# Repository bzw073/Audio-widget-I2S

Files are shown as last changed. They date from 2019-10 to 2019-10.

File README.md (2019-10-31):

# Audio-widget-I2S
**Interfata audio USB utilizand un AVR32 pe protocolul I2S**

## Introducere
>
>Inca din timpurile dinaintea erei digitale, consumatorii de audio **asa zisii audiofili** au fost in cautare de metode pentru reducerea la minim a distorsiunilor transmise catre difuzoare,si implicit,percepute de urechea umana.In vremea respectiva,data fiind si complexitatea destul de redusa a dispozitivelor,ideea reducerii distorsiunilor in sisteme era destul de limitata de topologiile propuse,de aceea aparitia sistemelor digitale de procesare in audio a dus la reducerea drastica a neajunsurilor semnalelor analogice.Pentru **puristi** , circuitele digitale si DSP-urile sunt considerate _un sacrilegiu_ adus audiofiliei,dar este unul justificat,deoarece in ciuda complexitatii mai ridicate fata de un circuit analog pur , sistemele digitale sunt mult mai eficiente fata de complementele sale,iar posibilitatea customizarii lor este foarte mare (spre deosebire de un circuit analogic unde,pentru a modifica o caracteristica trebuie regandit tot circuitul,in cazul unui circuit digital cu uC este doar o problema de software).

>Aparitia interfetelor audio s-a facut odata cu dezvoltarea PC-urilor si inregistrarea de muzica/sunete pe medii digitale , in pofida benzilor magnetice si a discurilor de vinil , deoarece era necesara o metoda de redare a sunetelor stocate pe calculatoarele vremii. De altfel,primele asa zise **placi de sunet** si-au facut aparitia prin calculatoare in jurul generatiei 80486 , cand deja exista o oarecare structura de operare stabila pe 16 biti , iar pentru o esantionare simpla a sunetelor erau arhisuficiente instructiunile implementate de Intel in procesoarele respective.
>>_Daca facem referinta la vremurile actuale,se poate spune ca practic nici nu se punea problema de calitate sau termenul de **Hi-Fi** in acele vremuri,dar acele sunete au reprezentat ceea ce urma sa fie boom-ul erei digitale_
>
>Ca si istorie a acestei ere in care traim,se pot scrie foarte multe lucruri deja cunoscute,asa ca voi incerca sa ma concentrez pe esential.

>Ideea de "calitate audio" pe digital a aparut in momentul lansarii pe piata mondiala a CD-ului (acel lucru care acum multora dintre noi ni se pare atat de outdated,ori chiar nu il mai folosim),dar el a avut cea mai mare influenta in aparitia de tehnologii de compresie si codare audio.Ca si concept,ideea de CD a aparut prin anul 1980 ,cand Philips si Sony au incheiat un parteneriat de cercetare in domeniul digital,dorindu-se un mediu de stocare unic transmisibil,care sa aibe un spatiu de stocare a informatiilor mult mai mare decat cel al dischetelor "floppy" si al benzilor magnetice,dar totusi sa nu coste cat un hard disk al vremurilor (memo: un hard disk de tip Winchester avea o capacitate de maxim 128MB , cantarea in jur de 15-20kg si era cam cat un desktop SFF actual ca dimensiuni si costa in jur de ~5.000 de dolari unul?).
>>Standardul CD a fost definitivat in jurul anului 1983,iar in urma intelegerii realizate intre cele 2 concerne se va realiza trecerea industriei audio catre acest mediu.

>Se pune problema "compresiei audio".In a nutshell,algoritmul de compresie audio se refera la un standard de scriere-redare a sunetelor pe calculatoare. Calculatoarele,la momentul respectiv avand sisteme de operare stabile precum UNIX si DOS (vorbind de anii '80,dar regula se aplica si in prezent pe sistemele actuale),pentru a reda sunetele stocate pe medii precum hard-diskul se folosesc de niste software numite **codec** .
>>Codecurile,in esenta,sunt niste pseudo-drivere pe care sistemul de operare le interpreteaza atunci cand se executa in sistem un fisier cu extensia ce corespunde codecului respectiv.
>>Adica,spre exemplu, avem un fisier cu extensia ".mp3" , SO va sti ca la instantierea acestui fisier va trebui sa apeleze un Codec LAME(Lame Ain't an MP3 Encoder - care este o derivatie imbunatatita de-a lungul anilor de diversi programatori din conceptul original gandit de institutul Fraunhofer din Germania).

>De altfel , toate procedeele de redare/compresie si extensiile de sistem au fost posibile datorita codarii PCM (Pulse Code Modulation).
PCM reprezinta transformarea semnalelor analogice in semnale digitale printr-un algoritm de esantionare constanta a amplitudinii semnalului analogic ,iar fiecare esantion este cuantizat la cea mai apropiata valoare dintr-o gama de cuante apropiate.
>>**Codarea PCM prezinta 2 proprietati ce determina calitatea conversiei semnalului original raportat la acesta : rata de esantionare a semnalului si _bit depth_,care reprezinta cantitatea de biti al fiecarui esantion realizat (un CD-Audio prezinta un bit depth de 16 biti per esantion , pe cand un Blu-ray sau DVD-Audio 24 de biti per esantion).**
>>> Extensiile posibile unei compresii PCM sunt ".wav" ,".L16",".PCM",".AIFF",".AU"

>Pe baza codarii/compresiei PCM a fisierelor audio, cei de la Philips au realizat in anul 1986 (si ulterior revizuit in 1996) un protocol de transmisie seriala al datelor audio intre dispozitive / circuite integrate , protocol care inca se foloseste cu succes si in prezent in dispozitivele audio. Este cunoscut sub acronimul I2S sau IIS **Inter-IC Sound** si se bazeaza pe o magistrala sincrona de transmisie de date (clockul de transmisie intre circuite este separat de magistrala de date,deci implicit receptorul nu mai are nevoie de un circuit suplimentar de refacere a frontului de ceas trimis de emitator).
>Protocolul este relativ usor de interpretat, in principal avem de-a face cu 3 semnale : bit clock line(**BCLK**) , word clock line (cunoscut sub denumirea oficiala de 'word select' **WS** sau 'left-right clock' **LRCLK** ) si cel putin o linie de date multiplexata **SD**

>>Adeseori se mai poate intalni peste cele 3 semnale cunoscute inca un semnal de tact (care nu face parte din protocol) cu rolul de a sincroniza operatiile interne ale DAC-urilor cu cele ale controllerului . Este gasit sub acronimul de "Master clock" **MCLK**
>>>Frecventa tipica de lucru se calculeaza dupa formula : **MCLK = 256 * LRCLK**

500px-I2S_Timing svg

###### Cum functioneaza protocolul:

>Semnalul de "Word Select" permite dispozitivului receptor sa 'vada' ce canal urmeaza sa fie trimis , deoarece I2S permite ca pe aceeasi linie de date sa fie trimise 2 canale,fiind un semnal cu factor de umplere 50% si frecventa egala cu cea de esantionare a semnalului trimis.
>>**Pentru semnale stereo , in brosura de specificatii a I2S se spune ca semnalul audio de pe canalul stang se transmite pe palierul de 0 al Word Select , iar canalul drept pe palierul de 1 . De obicei , semnalul "Word Select" este sincronizat dupa fronturile cazatoare ale semnalului BCLK , deoarece datele sunt zavorate pe fronturile crescatoare**.
>>
>Se stabileste semnul liniei de date si se codeaza in complement fata de 2 cu primul bit MSB-ul . **Acest lucru permite ca numarul de biti per cadru sa fie arbitrar , fara a fi nevoie de "negociere" intre emitator si receptor **.

## Specificatii montaj:

1.
 a)Microcontroller utilizat:  Atmel AT32UC3A3256 
 >>>  A complete system-on-chip 32-bit AVR microcontroller. It is designed for cost-sensitive embedded applications that require low power consumption, high code density and high performance.

 >>> The microcontroller's Memory Protection Unit (MPU) and fast, flexible interrupt controller support the latest real-time operating systems. Higher computation capabilities are achievable using a rich set of DSP instructions. The device incorporates on-chip flash and SRAM memories for secure and fast access. 64 KBytes of SRAM are directly coupled to the 32-bit AVR UC3 for performance optimization. Two blocks of 32 Kbytes SRAM are independently attached to the high speed bus matrix for real ping-pong management.

 >>> The microcontroller achieves exceptionally high data throughput by combining the multi-layered 32-bit AVR databus,128 KB on-chip SRAM with triple high speed interfaces, multi-channel peripheral, memory-to-memory DMA controller, high-speed USB embedded host, SD/SDIO card, MLC NAND flash with ECC, and SDRAM interfaces.

 >>> This device features 256KB internal high-speed flash and full-duplex multi-channel I2S audio interface.
 
 b) DAC utilizat: PCM5102A

 >>>The PCM510xA devices are a family of monolithic CMOS-integrated circuits that include a stereo digital-to-analog converter and additional support circuitry in a small TSSOP package. The PCM510xA devices use the latest generation of TI’s advanced segment-DAC architecture to achieve excellent dynamic performance and improved tolerance to clock jitter.

 c) Amplificator/buffer iesire folosit : TPA6120
 >>>In applications requiring a high-power output, very high fidelity headphone amplifier, the TPA6120A2 replaces a costly discrete design and allows music, not the amplifier, to be heard. The TPA6120A2’s current-feedback AB amplifier architecture delivers high bandwidth, extremely low noise, and up to 128dB of dynamic range.
 
2.Utilizeaza USB Audio Class 1 / 2.

3.Capabilitati de redare audio pana la 24bit/96kHz (bit depth / sampling rate).

4.Tensiune de alimentare: 5V

5.Consum max: 500mA 

### Constructie montaj:

Contructia se bazeaza pe un design modular , iar in acest sens voi concepe intregul sistem pe 4 placi:
 - una o va constitui interfata emulatoare usb-i2s
 - o placa pentru DAC si , eventual , buffere de iesire
 - o placa pentru amplificatorul final
 - o placa pentru alimentare suplimentara

Ideea conceperii montajului intr-un sistem modular este pentru imbunatatirea "lantului" pe decursul timpului (ex. realizarea unui DAC mai performant din perspectiva SNR / PSRR sau schimbarea unei surse liniare cu una in comutatie sau adaugarea de acumulatori pentru portabilitate etc.)

De altfel,un montaj modular poate presupune o asezare mai buna in cutie si,totodata, un ecranaj mai bun al partilor **mai sensibile** fata de circuitul de alimentare.

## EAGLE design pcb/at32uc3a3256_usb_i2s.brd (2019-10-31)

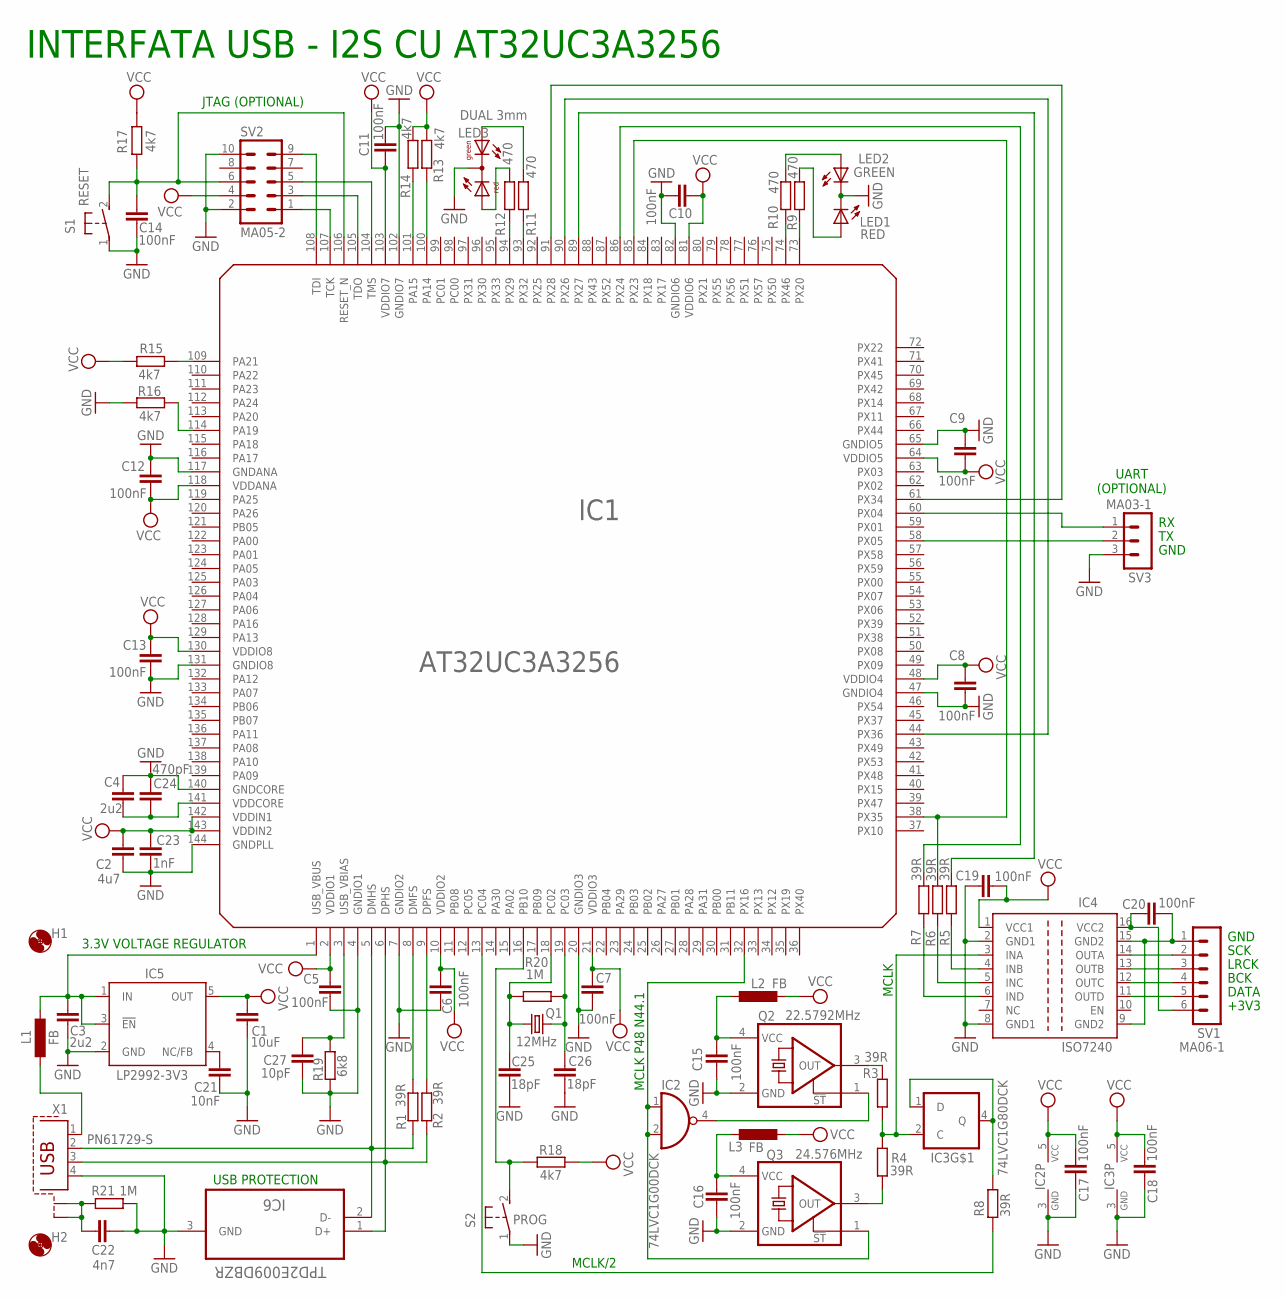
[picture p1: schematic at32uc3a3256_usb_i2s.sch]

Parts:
C1: 10uF; C0603
C2: 4u7; C0603
C3, C4: 2u2; C0603
C5, C6, C7, C8, C9, C10, C11, C12, C13, C14, C15, C16, C17, C18, C19, C20: 100nF; C0603
C21: 10nF; C0603
C22: 4n7; C0603
C23: 1nF; C0603
C24: 470pF; C0603
C25, C26: 18pF; C0603
C27: 10pF; C0603
H1, H2: MOUNT-HOLE3.2; 3,2
IC1: AT32UC3A3256; LQFP144
IC2: 74LVC1G00DCK; SC70-5
IC3: 74LVC1G80DCK; SC70-5
IC4: ISO7240; SO-16DW
IC5: LP2992-3V3; SOT23-DBV
IC6: TPD2E009DBZR; SOT95P237X112-3N
L1, L2, L3: FB; L2012C
LED1: RED; CHIPLED_0603
LED2: GREEN; CHIPLED_0603
LED3: DUAL 3mm; DUOLED5MM
Q1: 12MHz; CTS406
Q2: 22.5792MHz; CRYSTAL2.5X2
Q3: 24.576MHz; CRYSTAL2.5X2
R1, R2, R3, R4, R5, R6, R7, R8: 39R; R0603
R9, R10, R11, R12: 470; R0603
R13, R14, R15, R16, R17, R18: 4k7; R0603
R19: 6k8; R0603
R20, R21: 1M; R0603
S1: RESET; SWITCH-KSR
S2: PROG; SWITCH-KSR
SV1: MA06-1
SV2: MA05-2
SV3: MA03-1
X1: PN61729-S

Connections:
AD_LRCK: IC1.44 (PX36), IC1.90 (PX26)
AD_SCLK: IC1.61 (PX34), IC1.91 (PX28)
DA_LRCK: IC1.89 (PX27), R5.2
DA_SCLK: IC1.38 (PX35), IC1.85 (PX23), R6.2
GND: C1.2, C2.2, C3.2, C4.1, C5.2, C6.2, C7.2, C8.2, C9.1, C10.1, C11.1, C12.1, C13.1, C14.2, C15.1, C16.1, C17.2, C18.2, C19.1, C21.2, C22.2, C23.2, C24.1, C25.2, C26.2, C27.2, IC1.4 (GNDIO1), IC1.7 (GNDIO2), IC1.20 (GNDIO3), IC1.47 (GNDIO4), IC1.65 (GNDIO5), IC1.82 (GNDIO6), IC1.102 (GNDIO7), IC1.117 (GNDANA), IC1.131 (GNDIO8), IC1.140 (GNDCORE), IC1.144 (GNDPLL), IC2.3 (GND), IC3.3 (GND), IC4.2 (GND1), IC4.8 (GND1), IC5.2 (GND), IC6.3 (GND), LED1.C, LED2.C, LED3.K (C), Q2.2 (GND), Q3.2 (GND), R16.1, R19.1, R21.2, S1.1, S2.1, SV2.2, SV2.10, SV3.3, X1.4
GND2: C20.2, IC4.9 (GND2), IC4.15 (GND2), SV1.1
GPIO_05_LED2: IC1.94 (PX29), R12.1
GPIO_08_LED1: IC1.93 (PX32), R11.1
LRCK: IC4.4 (INB), R5.1
MCLK: IC3.2 (C), IC4.3 (INA), R3.1, R4.2
MCLK_MCU: IC1.13 (PC04), R8.1
MCLK_P48_N441: IC1.32 (PX16), IC2.1 (I0), IC2.2 (I1), Q3.1 (!ST)
unnamed: C15.2, L2.2, Q2.4 (VCC)
unnamed: IC1.5 (DMHS), IC6.2 (D-), R1.1, X1.2
unnamed: Q3.3 (OUT), R4.1
unnamed: Q2.3 (OUT), R3.2
unnamed: C16.2, L3.2, Q3.4 (VCC)
unnamed: IC1.6 (DPHS), IC6.1 (D+), R2.1, X1.3
unnamed: IC1.8 (DMFS), R1.2
unnamed: C26.1, IC1.19 (PC03), Q1.3 (2), R20.2
unnamed: C25.1, IC1.18 (PC02), Q1.1, R20.1
unnamed: IC1.9 (DPFS), R2.2
unnamed: C4.2, C24.2, IC1.141 (VDDCORE)
unnamed: IC1.108 (TDI), SV2.9
unnamed: IC1.114 (PA19), R16.2
unnamed: C22.1, R21.1, X1.S1, X1.S2
unnamed: C27.1, IC1.3 (USB_VBIAS), R19.2
unnamed: C20.1, IC4.16 (VCC2), SV1.6
unnamed: IC4.14 (OUTA), SV1.2
unnamed: IC4.13 (OUTB), SV1.3
unnamed: IC4.12 (OUTC), SV1.4
unnamed: LED1.A, R9.2
unnamed: LED2.A, R10.2
unnamed: IC1.74 (PX46), R10.1
unnamed: IC1.73 (PX20), R9.1
unnamed: IC1.109 (PA21), R15.2
unnamed: IC1.101 (PA15), R14.1
unnamed: IC1.100 (PA14), R13.1
unnamed: IC4.11 (OUTD), SV1.5
unnamed: IC4.5 (INC), R6.1
unnamed: IC1.86 (PX24), R7.2
unnamed: IC4.6 (IND), R7.1
unnamed: IC3.1 (D), IC3.4 (Q), R8.2
unnamed: L1.1, X1.1
unnamed: LED3.AG, R11.2
unnamed: C21.1, IC5.4 (NC/FB)
unnamed: LED3.AR, R12.2
unnamed: IC2.4 (O), Q2.1 (!ST)
NSRST: C14.1, IC1.106 (RESET_N), R17.1, S1.2, SV2.6
PROG: IC1.16 (PB10), R18.2, S2.2
TCK: IC1.107 (TCK), SV2.1
TDO: IC1.105 (TDO), SV2.3
TMS: IC1.104 (TMS), SV2.5
UART_RX: IC1.60 (PX04), SV3.1
UART_TX: IC1.58 (PX05), SV3.2
VBUS: C3.1, IC1.1 (USB_VBUS), IC5.1 (IN), IC5.3 (!EN), L1.2
VCC: C1.1, C2.1, C5.1, C6.1, C7.1, C8.1, C9.2, C10.2, C11.2, C12.2, C13.2, C17.1, C18.1, C19.2, C23.1, IC1.2 (VDDIO1), IC1.10 (VDDIO2), IC1.21 (VDDIO3), IC1.48 (VDDIO4), IC1.64 (VDDIO5), IC1.81 (VDDIO6), IC1.103 (VDDIO7), IC1.118 (VDDANA), IC1.130 (VDDIO8), IC1.142 (VDDIN1), IC1.143 (VDDIN2), IC2.5 (VCC), IC3.5 (VCC), IC4.1 (VCC1), IC5.5 (OUT), L2.1, L3.1, R13.2, R14.2, R15.1, R17.2, R18.1, SV2.4

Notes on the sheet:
GND
SCK
LRCK
BCK
DATA
+3V3
INTERFATA USB - I2S CU AT32UC3A3256
MCLK
MCLK/2
MCLK P48 N44.1
3.3V VOLTAGE REGULATOR
USB PROTECTION
JTAG (OPTIONAL)
UART (OPTIONAL)

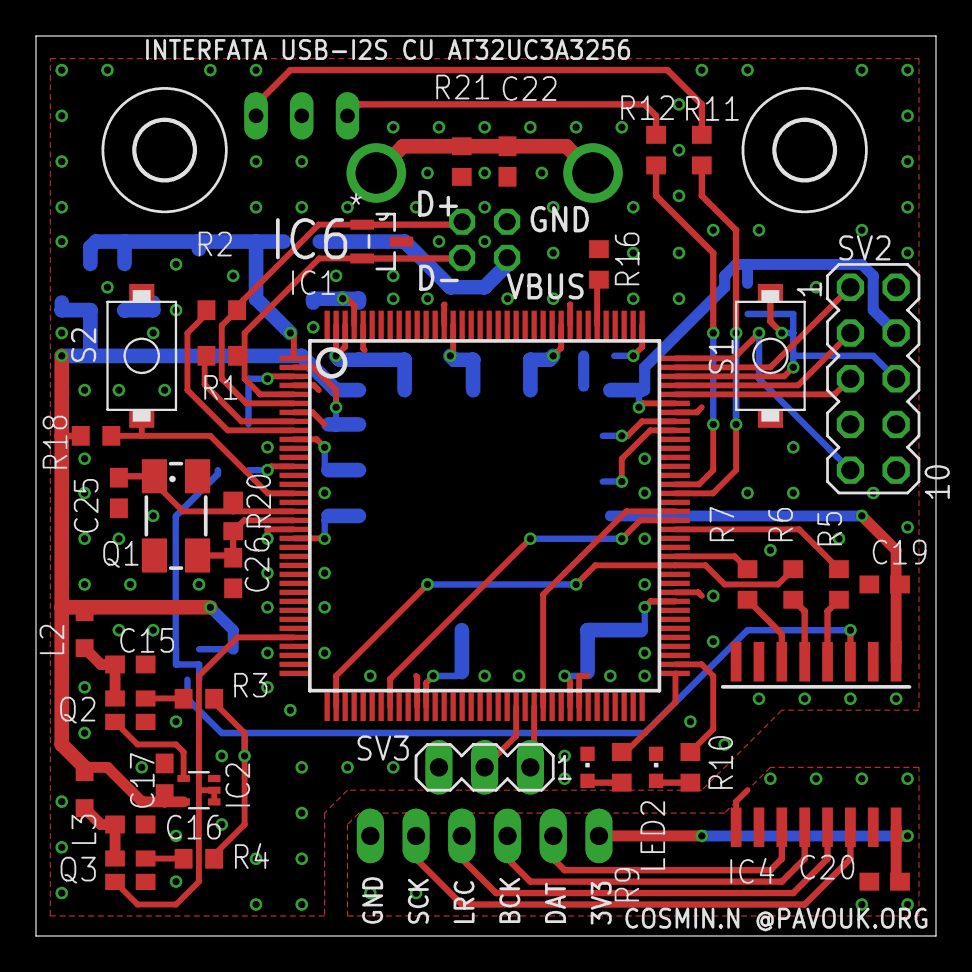
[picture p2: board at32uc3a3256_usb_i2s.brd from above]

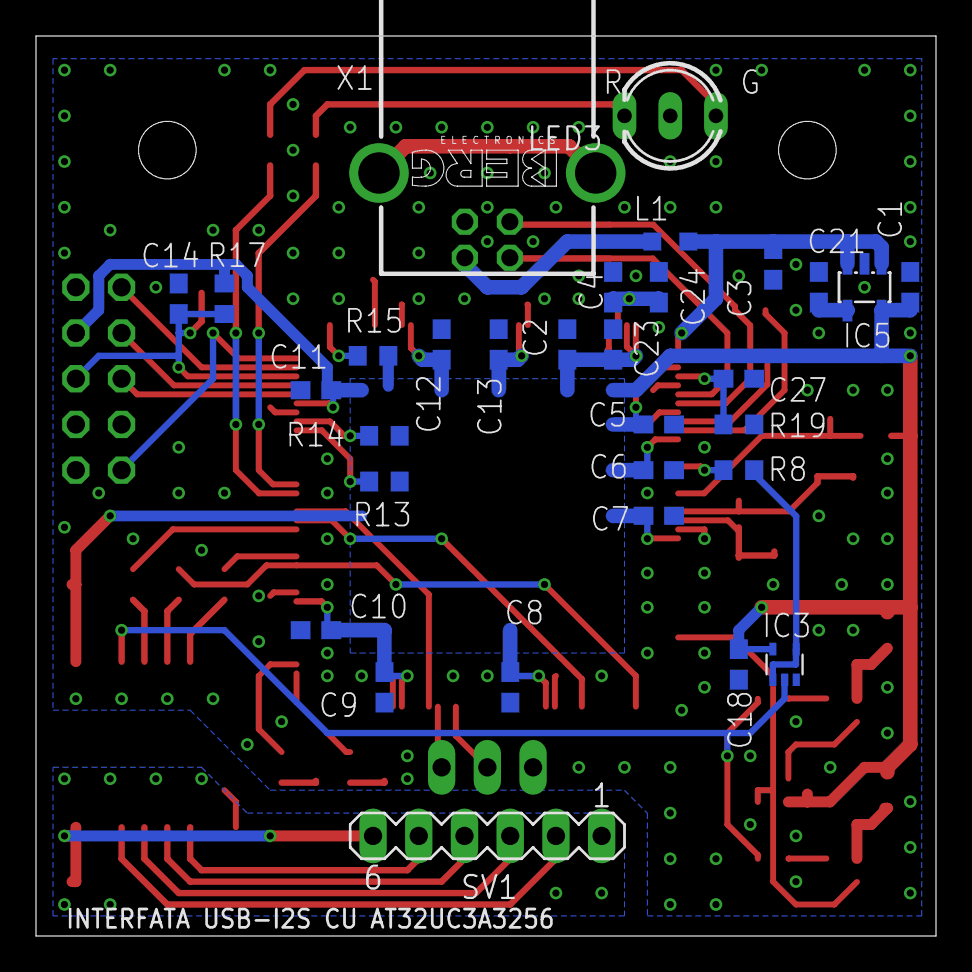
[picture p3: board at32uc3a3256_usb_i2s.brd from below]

Board: 2 copper layers, 50.0 x 50.0 mm, 71 parts (31 on the bottom side), 57 nets.

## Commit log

2019-10-29 Added schematic for I2S interface
    [at32uc3a3256_usb_i2s.sch]
2019-10-31 Added circuit construction memos
2019-10-31 Added interface pcb design
    [at32uc3a3256_usb_i2s.brd]
